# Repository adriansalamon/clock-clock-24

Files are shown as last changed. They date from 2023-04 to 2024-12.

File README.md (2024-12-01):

## My own ClockClock 24 replica

My own take/version of the ClockClock 24 by [Humans Since 1982](https://www.humanssince1982.com) - A digital clock made from 24 analog clocks.
All credit goes to them for coming up with such an awesome design.

Video (https://www.youtube.com/watch?v=78b-10ijSYw)

My version is made 100% from scratch using my own hardware design.
Mine is also slightly smaller, made to fit perfectly on my shelf.
This design uses 6 Arduino nanos, each in control of 4 individual
clocks, and an ESP32 which orchestrates and sends commands to all
Arduinos.

The physical clock is made from MDF, which was routed using a 3d
printed jig (I don't own a CNC). That process will not be published.

The software is still WIP and not finished.

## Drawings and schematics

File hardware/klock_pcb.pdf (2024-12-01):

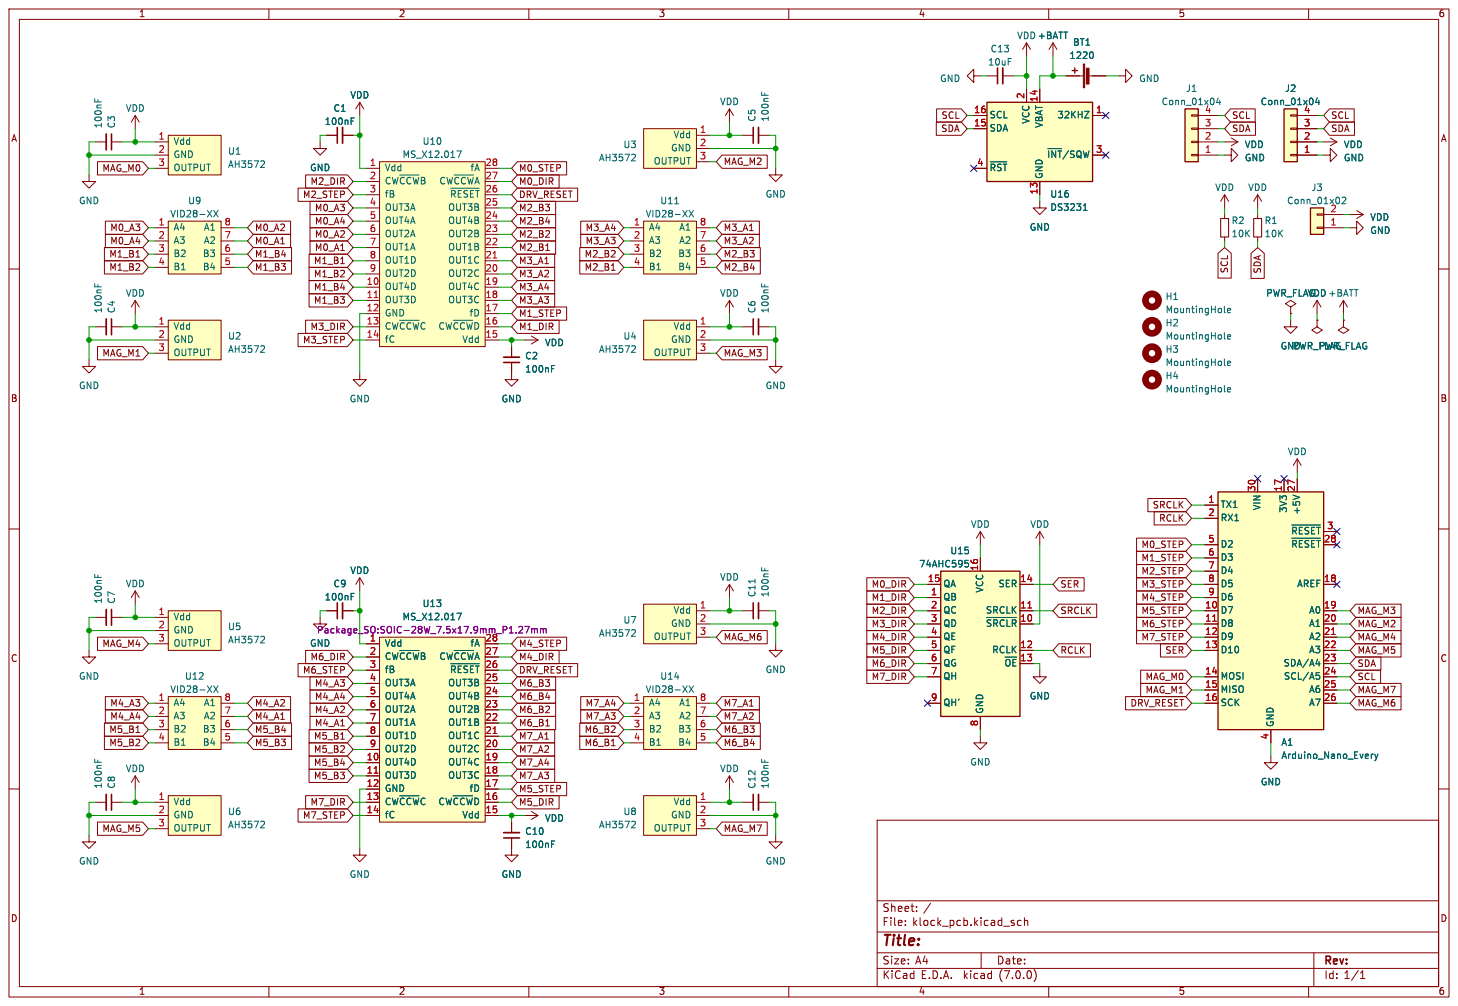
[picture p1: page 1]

Vdd 1 OUT4D 10 OUT3D 11 GND 12 CW~{CCW}C

Id: 1/1 Title: File: klock_pcb.kicad_sch Sheet: /

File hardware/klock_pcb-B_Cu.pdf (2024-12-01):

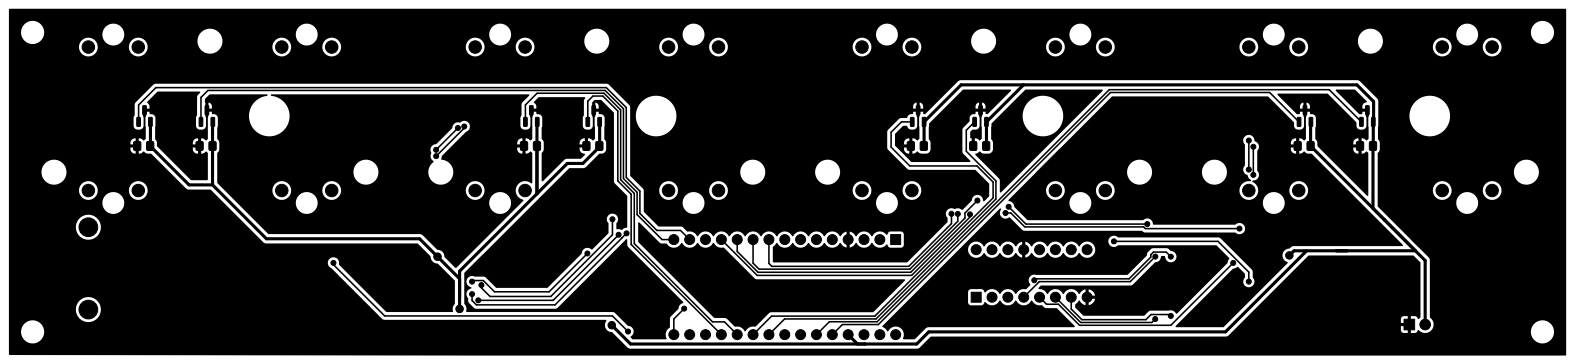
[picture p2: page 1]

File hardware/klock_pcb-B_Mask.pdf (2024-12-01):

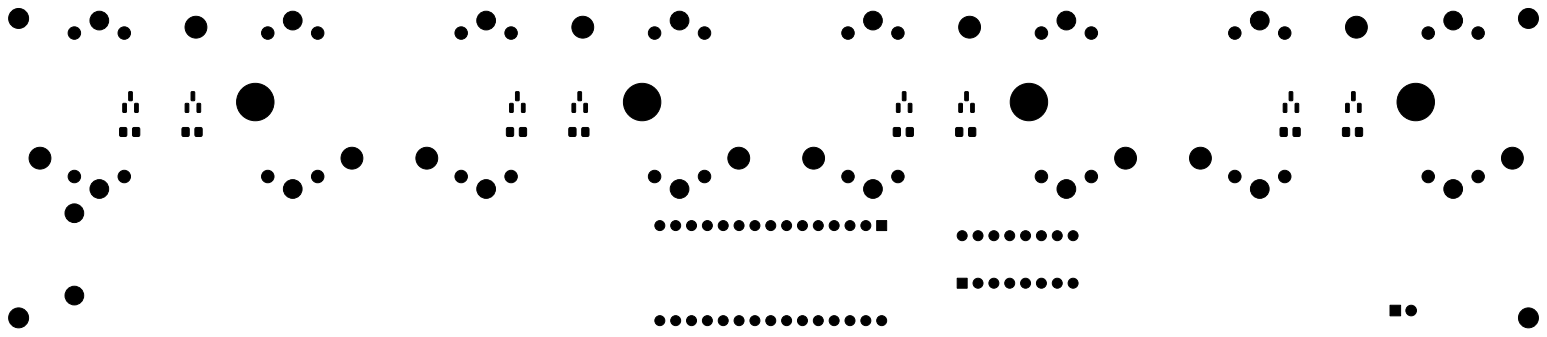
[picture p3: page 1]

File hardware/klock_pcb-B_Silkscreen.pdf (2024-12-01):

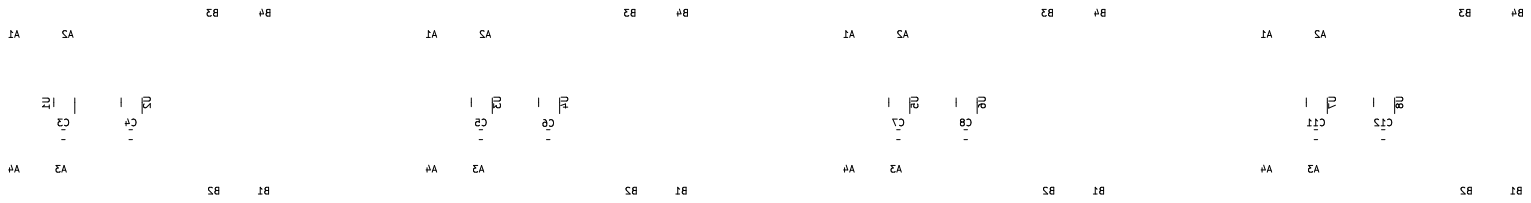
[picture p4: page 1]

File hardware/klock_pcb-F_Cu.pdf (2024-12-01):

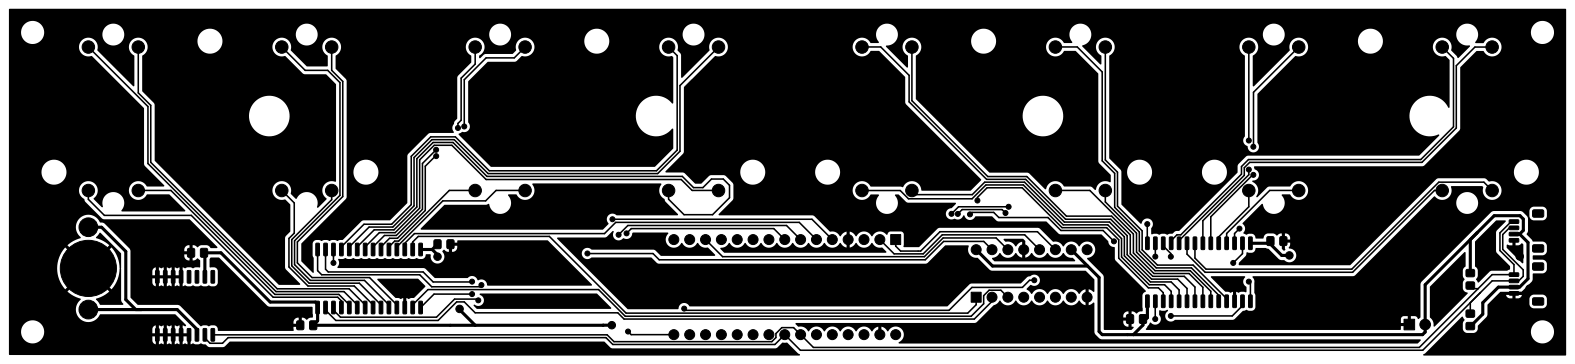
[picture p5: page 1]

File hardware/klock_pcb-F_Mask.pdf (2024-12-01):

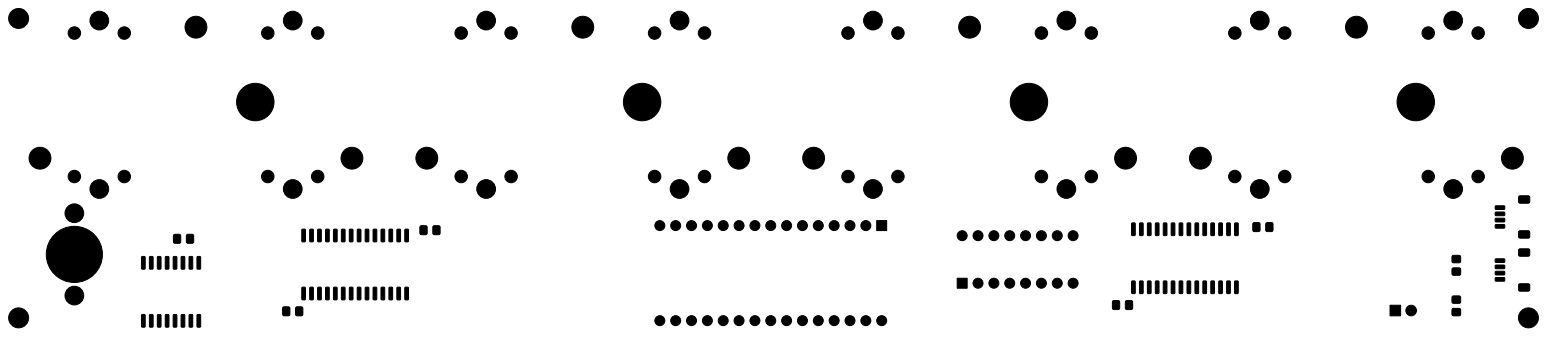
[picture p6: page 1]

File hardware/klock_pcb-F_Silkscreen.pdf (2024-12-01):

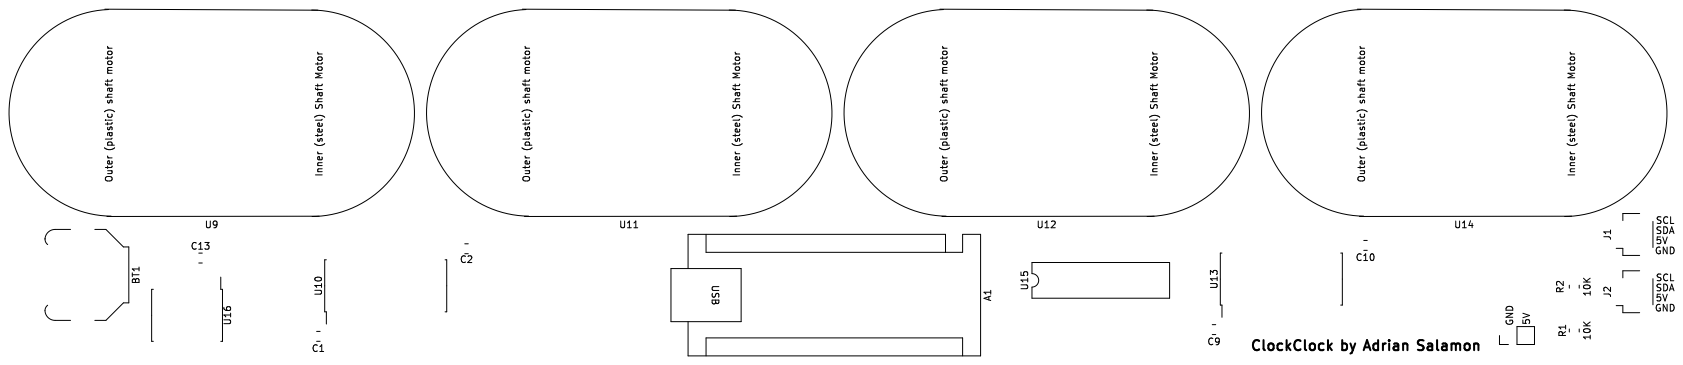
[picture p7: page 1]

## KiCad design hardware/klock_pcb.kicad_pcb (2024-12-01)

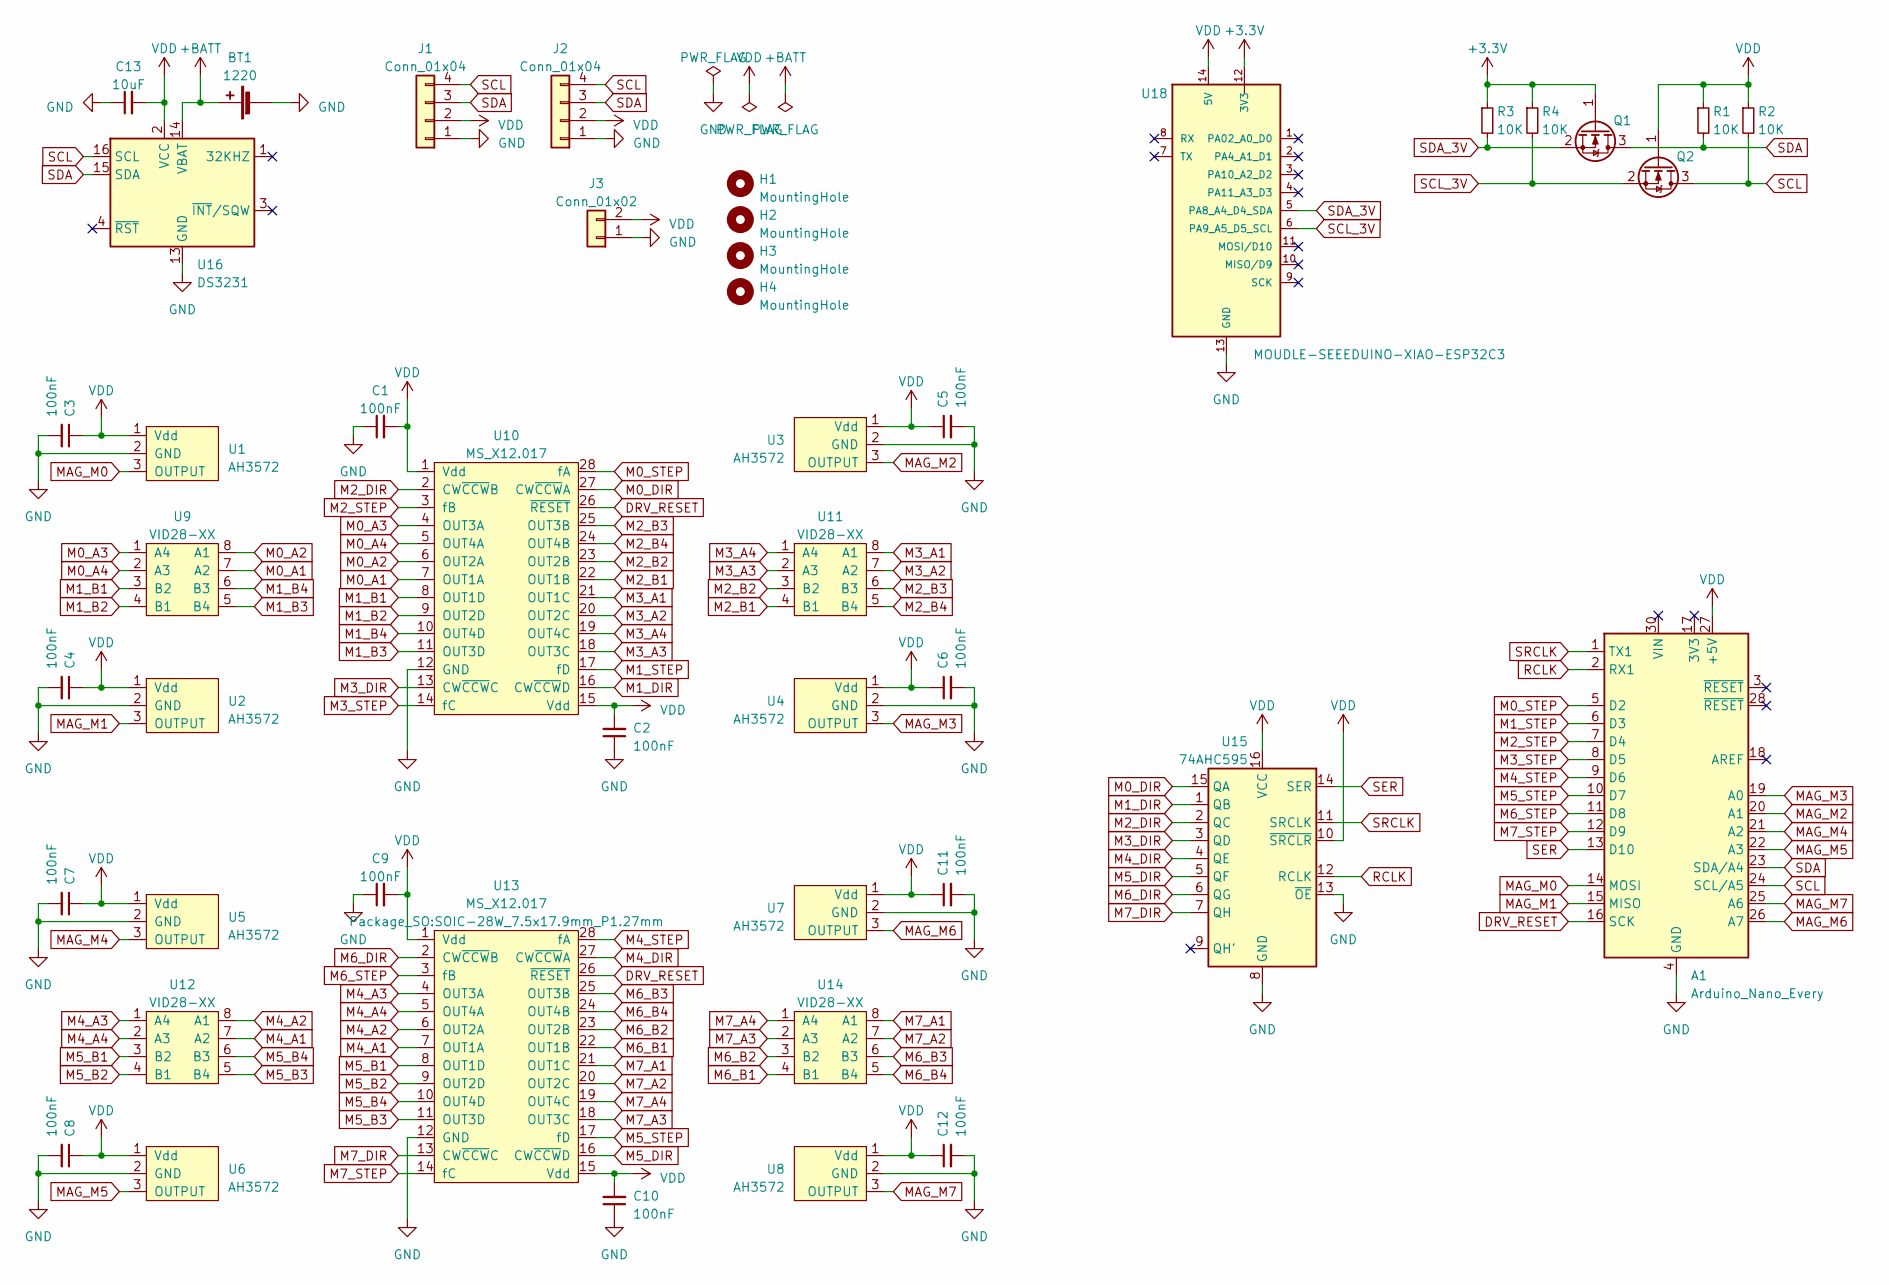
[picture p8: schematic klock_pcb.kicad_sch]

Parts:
A1: Arduino_Nano_Every; Arduino_Nano
BT1: 1220; BatteryHolder_Keystone_3001_1x12mm
C1, C2, C3, C4, C5, C6, C7, C8, C9, C10, C11, C12: 100nF; C_0805_2012Metric_Pad1.18x1.45mm_HandSolder
C13: 10uF; C_0805_2012Metric_Pad1.18x1.45mm_HandSolder
H1, H2, H3, H4: MountingHole; MountingHole_3.2mm_M3_Pad
J1, J2: Conn_01x04; JST_SH_SM04B-SRSS-TB_1x04-1MP_P1.00mm_Horizontal
J3: Conn_01x02; PinHeader_1x02_P2.54mm_Vertical
Q1, Q2: BSS138; SOT-23
R1, R2, R3, R4: 10K; R_0805_2012Metric_Pad1.20x1.40mm_HandSolder
U1, U2, U3, U4, U5, U6, U7, U8: AH3572; AH3572-SOT-23
U9, U11, U12, U14: VID28-XX; VID28-XX_DownMount
U10, U13: MS_X12.017; SOIC-28W_7.5x17.9mm_P1.27mm
U15: 74AHC595; DIP-16_W7.62mm
U16: DS3231; SOIC-16W_7.5x10.3mm_P1.27mm
U18: MOUDLE-SEEEDUINO-XIAO-ESP32C3; seeduino-MOUDLE14P-THT

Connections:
+3.3V: Q1.1 (G), R3.1, R4.1, U18.12 (3V3)
+BATT: BT1.1 (+), U16.14 (VBAT)
DRV_RESET: A1.16 (SCK), U10.26 (~RESET), U13.26 (~RESET)
GND: A1.4 (GND), A1.29 (GND), BT1.2 (-), C1.1, C2.1, C3.2, C4.2, C5.2, C6.2, C7.2, C8.2, C9.1, C10.1, C11.2, C12.2, C13.1, J1.1, J2.1, J3.1, U1.2 (GND), U2.2 (GND), U3.2 (GND), U4.2 (GND), U5.2 (GND), U6.2 (GND), U7.2 (GND), U8.2 (GND), U10.12 (GND), U13.12 (GND), U15.8 (GND), U15.13 (~OE), U16.5 (GND), U16.6 (GND), U16.7 (GND), U16.8 (GND), U16.9 (GND), U16.10 (GND), U16.11 (GND), U16.12 (GND), U16.13 (GND), U18.13 (GND)
M0_A1: U9.7 (A2), U10.7 (OUT1A)
M0_A2: U9.8 (A1), U10.6 (OUT2A)
M0_A3: U9.1 (A4), U10.4 (OUT3A)
M0_A4: U9.2 (A3), U10.5 (OUT4A)
M0_DIR: U10.27 (CW~CCWA), U15.15 (QA)
M0_STEP: A1.5 (D2), U10.28 (fA)
M1_B1: U9.3 (B2), U10.8 (OUT1D)
M1_B2: U9.4 (B1), U10.9 (OUT2D)
M1_B3: U9.5 (B4), U10.11 (OUT3D)
M1_B4: U9.6 (B3), U10.10 (OUT4D)
M1_DIR: U10.16 (CW~CCWD), U15.1 (QB)
M1_STEP: A1.6 (D3), U10.17 (fD)
M2_B1: U10.22 (OUT1B), U11.4 (B1)
M2_B2: U10.23 (OUT2B), U11.3 (B2)
M2_B3: U10.25 (OUT3B), U11.6 (B3)
M2_B4: U10.24 (OUT4B), U11.5 (B4)
M2_DIR: U10.2 (CW~CCWB), U15.2 (QC)
M2_STEP: A1.7 (D4), U10.3 (fB)
M3_A1: U10.21 (OUT1C), U11.8 (A1)
M3_A2: U10.20 (OUT2C), U11.7 (A2)
M3_A3: U10.18 (OUT3C), U11.2 (A3)
M3_A4: U10.19 (OUT4C), U11.1 (A4)
M3_DIR: U10.13 (CW~CCWC), U15.3 (QD)
M3_STEP: A1.8 (D5), U10.14 (fC)
M4_A1: U12.7 (A2), U13.7 (OUT1A)
M4_A2: U12.8 (A1), U13.6 (OUT2A)
M4_A3: U12.1 (A4), U13.4 (OUT3A)
M4_A4: U12.2 (A3), U13.5 (OUT4A)
M4_DIR: U13.27 (CW~CCWA), U15.4 (QE)
M4_STEP: A1.9 (D6), U13.28 (fA)
M5_B1: U12.3 (B2), U13.8 (OUT1D)
M5_B2: U12.4 (B1), U13.9 (OUT2D)
M5_B3: U12.5 (B4), U13.11 (OUT3D)
M5_B4: U12.6 (B3), U13.10 (OUT4D)
M5_DIR: U13.16 (CW~CCWD), U15.5 (QF)
M5_STEP: A1.10 (D7), U13.17 (fD)
M6_B1: U13.22 (OUT1B), U14.4 (B1)
M6_B2: U13.23 (OUT2B), U14.3 (B2)
M6_B3: U13.25 (OUT3B), U14.6 (B3)
M6_B4: U13.24 (OUT4B), U14.5 (B4)
M6_DIR: U13.2 (CW~CCWB), U15.6 (QG)
M6_STEP: A1.11 (D8), U13.3 (fB)
M7_A1: U13.21 (OUT1C), U14.8 (A1)
M7_A2: U13.20 (OUT2C), U14.7 (A2)
M7_A3: U13.18 (OUT3C), U14.2 (A3)
M7_A4: U13.19 (OUT4C), U14.1 (A4)
M7_DIR: U13.13 (CW~CCWC), U15.7 (QH)
M7_STEP: A1.12 (D9), U13.14 (fC)
MAG_M0: A1.14 (MOSI), U1.3 (OUTPUT)
MAG_M1: A1.15 (MISO), U2.3 (OUTPUT)
MAG_M2: A1.20 (A1), U3.3 (OUTPUT)
MAG_M3: A1.19 (A0), U4.3 (OUTPUT)
MAG_M4: A1.21 (A2), U5.3 (OUTPUT)
MAG_M5: A1.22 (A3), U6.3 (OUTPUT)
MAG_M6: A1.26 (A7), U7.3 (OUTPUT)
MAG_M7: A1.25 (A6), U8.3 (OUTPUT)
RCLK: A1.2 (RX1), U15.12 (RCLK)
SCL: A1.24 (SCL/A5), J1.4, J2.4, Q2.3 (D), R2.2, U16.16 (SCL)
SCL_3V: Q2.2 (S), R4.2, U18.6 (PA9_A5_D5_SCL)
SDA: A1.23 (SDA/A4), J1.3, J2.3, Q1.3 (D), R1.2, U16.15 (SDA)
SDA_3V: Q1.2 (S), R3.2, U18.5 (PA8_A4_D4_SDA)
SER: A1.13 (D10), U15.14 (SER)
SRCLK: A1.1 (TX1), U15.11 (SRCLK)
VDD: A1.27 (+5V), C1.2, C2.2, C3.1, C4.1, C5.1, C6.1, C7.1, C8.1, C9.2, C10.2, C11.1, C12.1, C13.2, J1.2, J2.2, J3.2, Q2.1 (G), R1.1, R2.1, U1.1 (Vdd), U2.1 (Vdd), U3.1 (Vdd), U4.1 (Vdd), U5.1 (Vdd), U6.1 (Vdd), U7.1 (Vdd), U8.1 (Vdd), U10.1 (Vdd), U10.15 (Vdd), U13.1 (Vdd), U13.15 (Vdd), U15.10 (~SRCLR), U15.16 (VCC), U16.2 (VCC), U18.14 (5V)

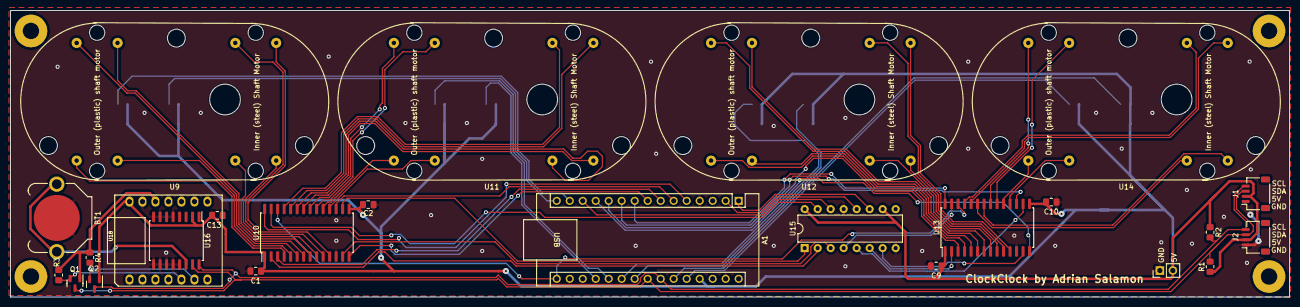
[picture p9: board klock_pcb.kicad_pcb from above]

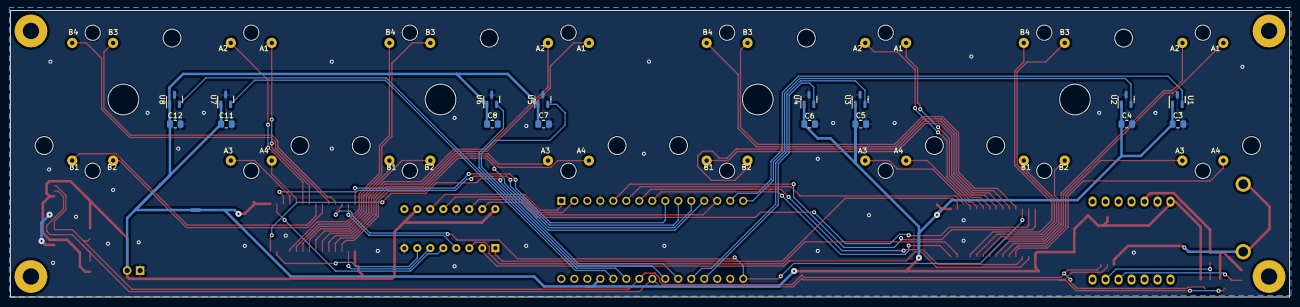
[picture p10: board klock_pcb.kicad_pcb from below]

Board: 2 copper layers, 250.0 x 56.0 mm, 45 parts (16 on the bottom side), 68 nets.

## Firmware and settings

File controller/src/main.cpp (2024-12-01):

#include <WiFi.h>
#include <ESPmDNS.h>
#include <WiFiUdp.h>
#include <ArduinoOTA.h>

#include "clock_manager.h"
#include "digits.h"
#include "web_server.h"
#include "ntp.h"

const char *ssid = "Crookienet_b22";
const char *password = "Crookshanks4301";

ClockWebServer web_server;

void setup()
{
  // initialize digital pin LED_BUILTIN as an output.

  Serial.begin(9600);
  Serial.println("Booting");

  WiFi.mode(WIFI_STA);
  WiFi.begin(ssid, password);
  while (WiFi.waitForConnectResult() != WL_CONNECTED)
  {
    Serial.println("Connection Failed! Rebooting...");
    delay(5000);
    ESP.restart();
  }

  ArduinoOTA
      .onStart([]()
               {
      String type;
      if (ArduinoOTA.getCommand() == U_FLASH)
        type = "sketch";
      else // U_SPIFFS
        type = "filesystem";

      // NOTE: if updating SPIFFS this would be the place to unmount SPIFFS using SPIFFS.end()
      Serial.println("Start updating " + type); })
      .onEnd([]()
             { Serial.println("\nEnd"); })
      .onProgress([](unsigned int progress, unsigned int total)
                  { Serial.printf("Progress: %u%%\r", (progress / (total / 100))); })
      .onError([](ota_error_t error)
               {
      Serial.printf("Error[%u]: ", error);
      if (error == OTA_AUTH_ERROR) Serial.println("Auth Failed");
      else if (error == OTA_BEGIN_ERROR) Serial.println("Begin Failed");
      else if (error == OTA_CONNECT_ERROR) Serial.println("Connect Failed");
      else if (error == OTA_RECEIVE_ERROR) Serial.println("Receive Failed");
      else if (error == OTA_END_ERROR) Serial.println("End Failed"); });

  ArduinoOTA.begin();

  Serial.println("Ready");
  Serial.print("IP address: ");
  Serial.println(WiFi.localIP());

  begin_NTP();
  setSyncProvider(get_NTP_time);
  // Sync every 30 minutes
  setSyncInterval(60 * 30);

  Wire.begin();
  web_server.begin(&clock_manager);

  clock_manager.setHourDirection(CLOCKWISE1);
  clock_manager.setMinuteDirection(COUNTERCLOCKWISE1);
  clock_manager.setHourSpeed(800.0);
  clock_manager.setMinuteSpeed(1400.0);

  clock_manager.sendFullClocks();
  // delay(15000);

  pinMode(LED_BUILTIN, OUTPUT);
}

int digit_index = 0;
unsigned long time_last;
int last_hour = -1;
int last_minute = -1;

#define SECOND 1000

// the loop function runs over and over again forever
void loop()
{
  ArduinoOTA.handle();
  web_server.update();

  if (last_hour != hour() || last_minute != minute())
  {
    last_hour = hour();
    last_minute = minute();
    clock_manager.setTime(last_hour, last_minute);
    if (clock_manager.getConfig().set_mode != MANUAL)
    {
      clock_manager.sendFullClocks();
    }
  }
}

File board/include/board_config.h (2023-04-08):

#ifndef CONFIG_H
#define CONFIG_H

// CHANGE THIS FOR EACH BOARD
#define I2C_ADDRESS 0x06
#define INVERTED false


#define MAG_THRESHOLD 10

typedef struct mag_pin {
    uint8_t pin;
    bool analog;
} t_mag_pin;

#define N_STEPS 4320 // 360 degrees * 12 microsteps

#define A1_STEP 2
#define A1_DIR 0
#define A1_MAG mag_pin{12, false}

#define B1_STEP 3
#define B1_DIR 1
#define B1_MAG mag_pin{11, false}

#define A2_STEP 4
#define A2_DIR 2
#define A2_MAG mag_pin{15, false}

#define B2_STEP 5
#define B2_DIR 3
#define B2_MAG mag_pin{14, false}


#define A3_STEP 6
#define A3_DIR 4
#define A3_MAG mag_pin{17, false}


#define B3_STEP 7
#define B3_DIR 5
#define B3_MAG mag_pin{16, false}


#define A4_STEP 8
#define A4_DIR 6
#define A4_MAG mag_pin{A7, true}


#define B4_STEP 9
#define B4_DIR 7
#define B4_MAG mag_pin{A6, true}


#define RESET 13

#endif // CONFIG_H

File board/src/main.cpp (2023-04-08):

/*
 * Blink
 * Turns on an LED on for one second,
 * then off for one second, repeatedly.
 */

#include <Arduino.h>
#include <Wire.h>
#include "i2c.h"
#include "board.h"
#include "clock_accel_stepper.h"

const t_clock default_clock = {0, 0, 1000, 1000, 300, 300, CLOSEST, CLOSEST};

t_full_clock target_clocks;
t_full_clock current_clocks;
int current_clock = 0;

void receiveEvent(int howMany)
{
    
    if (howMany >= sizeof(t_half_clock))
    {
        t_half_clock tmp_state;
        I2C_readAnything(tmp_state);

        for (uint8_t i = 0; i < 2; i++)
        {
            target_clocks.clocks[current_clock + i] = tmp_state.clocks[i];
            target_clocks.change_counter[current_clock + i] = tmp_state.change_counter[i];
        }

        current_clock += 2;
        if (current_clock >= NUM_CLOCKS)
            current_clock = 0;
    }
}

void setup()
{
    pinMode(LED_BUILTIN, OUTPUT);
    board_begin();

    target_clocks = {{default_clock, default_clock, default_clock, default_clock}, {0, 0, 0, 0}};
    current_clocks = {{default_clock, default_clock, default_clock, default_clock}, {0, 0, 0, 0}};

    for (uint8_t i = 0; i < NUM_CLOCKS; i++)
        set_clock(i, current_clocks.clocks[i]);
    
    for (uint8_t i = 0; i < NUM_CLOCKS; i++)
        zero_clock(i);

    for (uint8_t i = 0; i < NUM_CLOCKS; i++)
        set_clock(i, current_clocks.clocks[i]);
    

    Wire.begin(I2C_ADDRESS);
    Wire.onReceive(receiveEvent);
}

void loop()
{
    board_loop();

    for (uint8_t i = 0; i < NUM_CLOCKS; i++)
    {
        if (!clock_is_running(i) && current_clocks.change_counter[i] != target_clocks.change_counter[i])
        {
            current_clocks.clocks[i] = target_clocks.clocks[i];
            current_clocks.change_counter[i] = target_clocks.change_counter[i];

            set_clock(i, current_clocks.clocks[i]);
        }
    }
}

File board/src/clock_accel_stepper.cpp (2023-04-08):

#include "clock_accel_stepper.h"
#include "clock_state.h"

ClockAccelStepper::ClockAccelStepper(uint8_t interface, uint8_t pin1, uint8_t pin2, t_mag_pin mag_pin, ShiftRegister74HC595<1> *sr)
    : AccelStepper(interface, pin1, pin2)
{
    _sr = sr;
    _mag_pin = mag_pin;
    pinMode(_mag_pin.pin, INPUT_PULLUP);
};

void ClockAccelStepper::enableOutputs()
{
    pinMode(_pin[0], OUTPUT);
}

void ClockAccelStepper::setOutputPins(uint8_t mask)
{
    // Set step pin using port registers for speed
    _step = (mask & (1 << 0)) ? (HIGH ^ _pinInverted[0]) : (LOW ^ _pinInverted[0]);
    if (_pin[0] < 8)
        PORTD = (PORTD & ~(1 << _pin[0])) | (_step << _pin[0]);
    else
        PORTB = (PORTB & ~(1 << (_pin[0] - 8))) | (_step << (_pin[0] - 8));

    // Sed the direction pin using the shift register. We only need to do this if the direction has changed.
    _dir = (mask & (1 << 1)) ? (HIGH ^ _pinInverted[1]) : (LOW ^ _pinInverted[1]);
    if (_sr->get(_pin[1]) != _dir)
        _sr->set(_pin[1], _dir);
}

void ClockAccelStepper::setReverse(bool reverse)
{
    _reverse = reverse;
}

int ClockAccelStepper::calcAngleClockwise(int angle_1, int angle_2)
{
    int delta = (angle_2 - angle_1) % 360;
    return (delta < 0) ? 360 + delta : delta;
}

int ClockAccelStepper::calcAngleCounterClockwise(int angle_1, int angle_2)
{
    int delta = (angle_1 - angle_2) % 360;
    return (delta < 0) ? 360 + delta : delta;
}

void ClockAccelStepper::moveToAngle(int angle, int direction)
{
    int delta;
    uint8_t multiplier = 0;

    if (direction <= CLOCKWISE3)
    {
        delta = calcAngleClockwise(_current_angle, angle);
        multiplier = direction;
    }
    else if (direction <= COUNTERCLOCKWISE3)
    {
        delta = calcAngleCounterClockwise(_current_angle, angle);
        multiplier = direction - COUNTERCLOCKWISE;
    }
    else if (direction == CLOSEST)
    {
        int delta_cw = calcAngleClockwise(_current_angle, angle);
        int delta_ccw = calcAngleCounterClockwise(_current_angle, angle);
        direction = (delta_cw < delta_ccw) ? CLOCKWISE : COUNTERCLOCKWISE;
        delta = (delta_cw < delta_ccw) ? delta_cw : delta_ccw;
    }
    else if (direction == ZERO)
    {
        zero();
        return;
    }

    _current_angle = angle;
    int steps = delta * 12; // Microstepping 12x

    if (direction <= CLOCKWISE3)
        steps = steps + (N_STEPS * multiplier);
    else if (direction <= COUNTERCLOCKWISE3)
        steps = -1 * (steps + (N_STEPS * multiplier));

    move(steps * (_reverse ? -1 : 1));
}

void ClockAccelStepper::zero()
{
    _zeroing = true;

    while (_zeroing)
    {

        while (_mag_active())
        {
            move(-200);
            run();
        }

        while (!_mag_active())
        {
            move(200);
            run();
        }
        int pos = currentPosition();

        while (_mag_active())
        {
            move(200);
            run();
        }

        while (!_mag_active())
        {
            move(-200);
            run();
        }
        int end_pos = currentPosition();

        runToNewPosition((pos + end_pos) / 2);

#if INVERTED
        _current_angle = 270;
#else
        _current_angle = 90;
#endif

        _zeroing = false;
    }
}

bool ClockAccelStepper::_mag_active()
{
    if (_mag_pin.analog)
        return analogRead(_mag_pin.pin) < MAG_THRESHOLD;
    else
        return digitalRead(_mag_pin.pin) == LOW;
}

bool ClockAccelStepper::isZeroing()
{
    return _zeroing;
}

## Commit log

2023-03-24 working with i2c
2024-12-01 add hardware files
    [klock_pcb-B_Cu.gbr, klock_pcb-B_Mask.gbr, klock_pcb-B_Paste.gbr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]
